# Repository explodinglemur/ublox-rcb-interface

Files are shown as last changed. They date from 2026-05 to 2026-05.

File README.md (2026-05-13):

# ublox-rcb-interface
USB/RS232 interface board for F9P/M8T and other ublox RCB eval boards

Provides TX out and PPS from receiver to both USB and RS232 interfaces, and jumper-selectable TX from either USB or RS232 to receiver.

USB interface may also be disabled so it does not enumerate and only provides power.

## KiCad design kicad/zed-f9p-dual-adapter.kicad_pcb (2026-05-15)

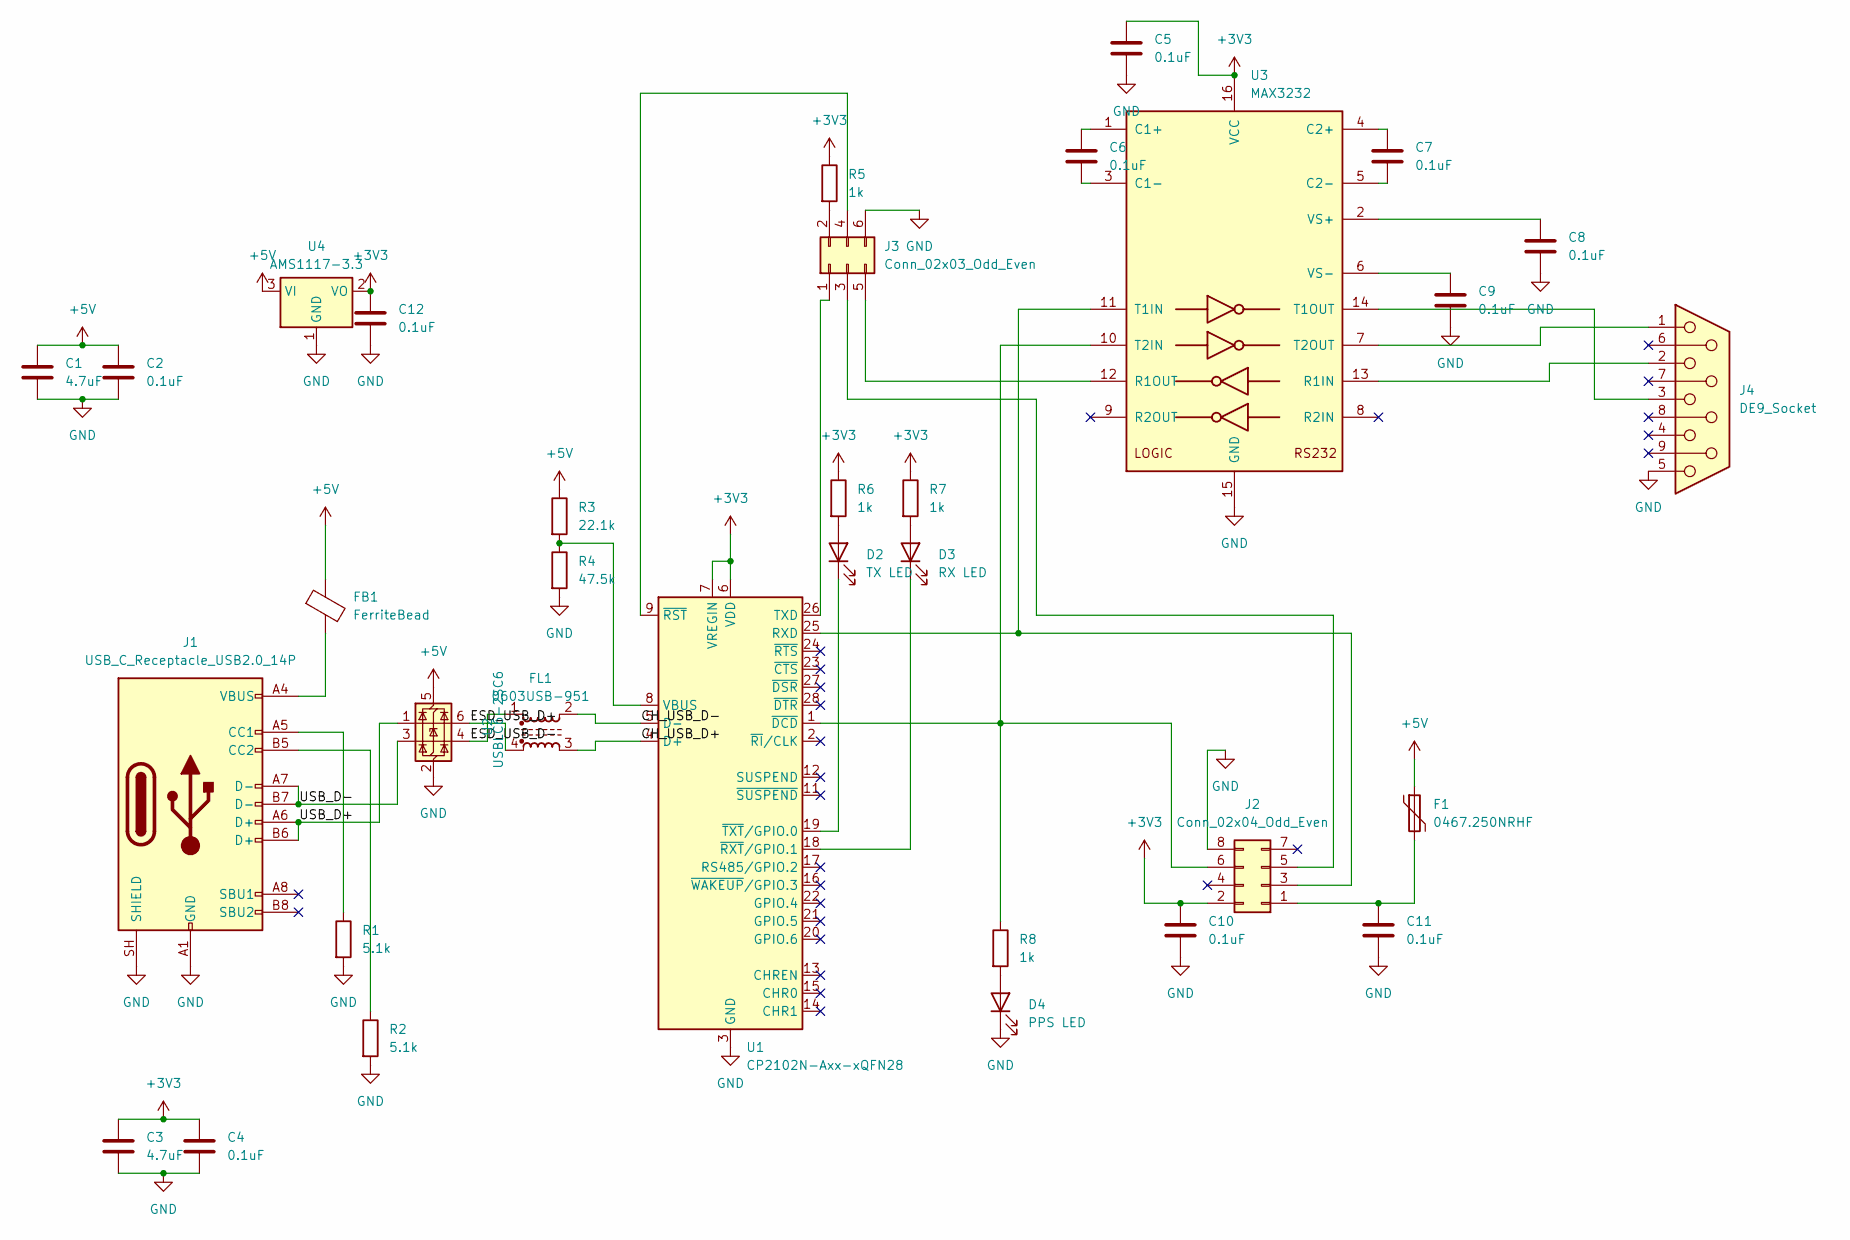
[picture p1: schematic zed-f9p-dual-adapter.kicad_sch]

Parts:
C1, C3: 4.7uF; C_0402_1005Metric
C2, C4, C5, C6, C7, C8, C9, C10, C11, C12: 0.1uF; C_0402_1005Metric
D2: TX LED; LED_0402_1005Metric
D3: RX LED; LED_0402_1005Metric
D4: PPS LED; LED_0402_1005Metric
F1: 0467.250NRHF; Fuse_0603_1608Metric
FB1: FerriteBead; L_0805_2012Metric
FL1: 0603USB-951; L_CommonModeChoke_Coilcraft_0603USB
J1: USB_C_Receptacle_USB2.0_14P; USB_C_Receptacle_G-Switch_GT-USB-7010ASV
J2: Conn_02x04_Odd_Even; PinSocket_2x04_P2.00mm_Vertical_SMD
J3: Conn_02x03_Odd_Even; PinHeader_2x03_P2.54mm_Vertical_SMD
J4: DE9_Socket; DSUB-9_Socket_EdgeMount_P2.77mm
R1, R2: 5.1k; R_0402_1005Metric
R3: 22.1k; R_0402_1005Metric
R4: 47.5k; R_0402_1005Metric
R5, R6, R7, R8: 1k; R_0402_1005Metric
U1: CP2102N-Axx-xQFN28; QFN-28-1EP_5x5mm_P0.5mm_EP3.35x3.35mm
U2: USBLC6-2SC6; SOT-666
U3: MAX3232; SSOP-16_5.3x6.2mm_P0.65mm
U4: AMS1117-3.3; SOT-223-3_TabPin2

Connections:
+3V3: C3.1, C4.1, C5.1, C10.1, C12.1, J2.2, R5.1, R6.1, R7.1, U1.6 (VDD), U1.7 (VREGIN), U3.16 (VCC), U4.2 (VO)
+5V: C1.1, C2.1, F1.1, FB1.1, R3.1, U2.5 (VBUS), U4.3 (VI)
/CH_USB_D+: FL1.3, U1.4 (D+)
/CH_USB_D-: FL1.2, U1.5 (D-)
/ESD_USB_D+: FL1.4, U2.6 (I/O1)
/ESD_USB_D-: FL1.1, U2.4 (I/O2)
/USB_D+: J1.A6 (D+), J1.B6 (D+), U2.1 (I/O1)
/USB_D-: J1.A7 (D-), J1.B7 (D-), U2.3 (I/O2)
GND: C1.2, C2.2, C3.2, C4.2, C5.2, C8.2, C9.2, C10.2, C11.2, C12.2, D4.1 (K), J1.A1 (GND), J1.A12 (GND), J1.B1 (GND), J1.B12 (GND), J1.SH (SHIELD), J2.8, J3.6, J4.5, R1.2, R2.2, R4.2, U1.3 (GND), U1.29 (GND), U2.2 (GND), U3.15 (GND), U4.1 (GND)
unnamed: D2.2 (A), R6.2
unnamed: D2.1 (K), U1.19 (~TXT/GPIO.0)
unnamed: D3.2 (A), R7.2
unnamed: D3.1 (K), U1.18 (~RXT/GPIO.1)
unnamed: D4.2 (A), R8.2
unnamed: FB1.2, J1.A4 (VBUS), J1.A9 (VBUS), J1.B4 (VBUS), J1.B9 (VBUS)
unnamed: J1.A5 (CC1), R1.1
unnamed: J1.B5 (CC2), R2.1
unnamed: C11.1, F1.2, J2.1
unnamed: J2.3, U1.25 (RXD), U3.11 (T1IN)
unnamed: J2.5, J3.3
unnamed: J2.6, R8.1, U1.1 (~DCD), U3.10 (T2IN)
unnamed: J3.1, U1.26 (TXD)
unnamed: J3.2, R5.2
unnamed: J3.4, U1.9 (~RST)
unnamed: J3.5, U3.12 (R1OUT)
unnamed: R3.2, R4.1, U1.8 (VBUS)
unnamed: C6.1, U3.1 (C1+)
unnamed: C6.2, U3.3 (C1-)
unnamed: C7.1, U3.4 (C2+)
unnamed: C7.2, U3.5 (C2-)
unnamed: J4.2, U3.13 (R1IN)
unnamed: J4.3, U3.14 (T1OUT)
unnamed: J4.1, U3.7 (T2OUT)
unnamed: C8.1, U3.2 (VS+)
unnamed: C9.1, U3.6 (VS-)

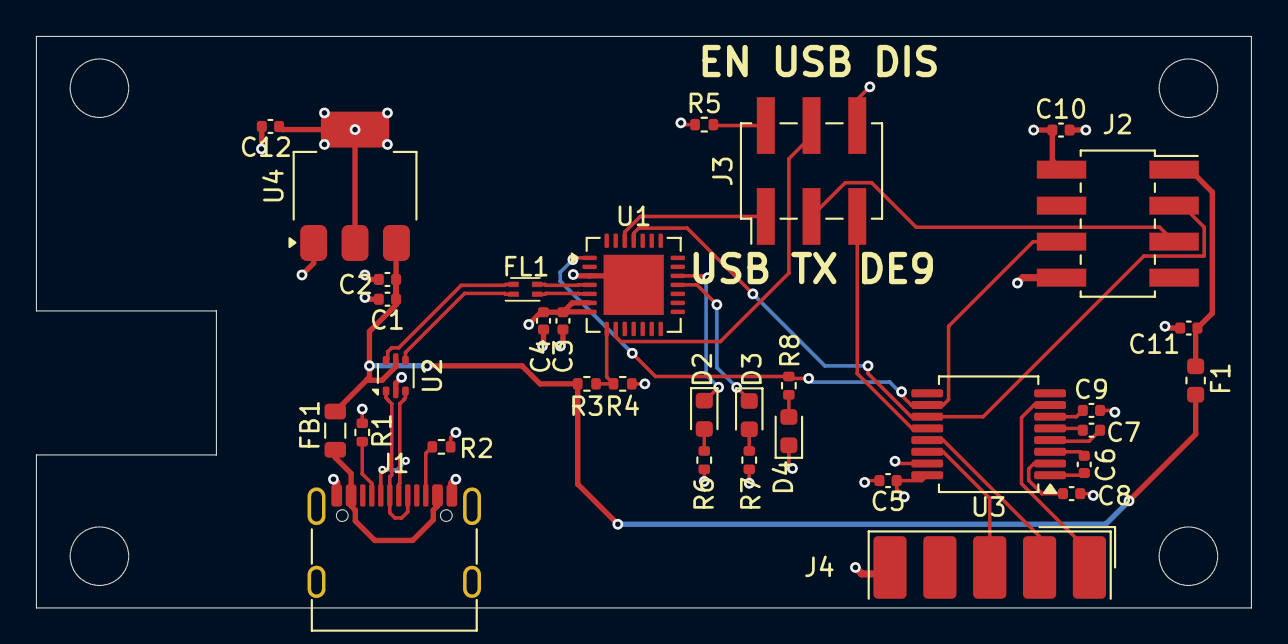
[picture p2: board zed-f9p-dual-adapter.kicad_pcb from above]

Board: 4 copper layers, 67.5 x 31.8 mm, 34 parts (0 on the bottom side), 35 nets.

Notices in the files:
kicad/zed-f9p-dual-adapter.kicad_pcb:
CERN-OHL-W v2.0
